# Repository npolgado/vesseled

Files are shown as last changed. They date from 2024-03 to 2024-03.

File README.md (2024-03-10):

# vesseled
addressable led code and hardware source. using addressable LEDS and creating a custom board to control and productize

Hardware:
- [x] Base prototyped idea
- [ ] Create a custom board to control addressable LEDS

Software:
- [x] Basic LED control
- [ ] track mouse poisition
- [ ] more input based lighting

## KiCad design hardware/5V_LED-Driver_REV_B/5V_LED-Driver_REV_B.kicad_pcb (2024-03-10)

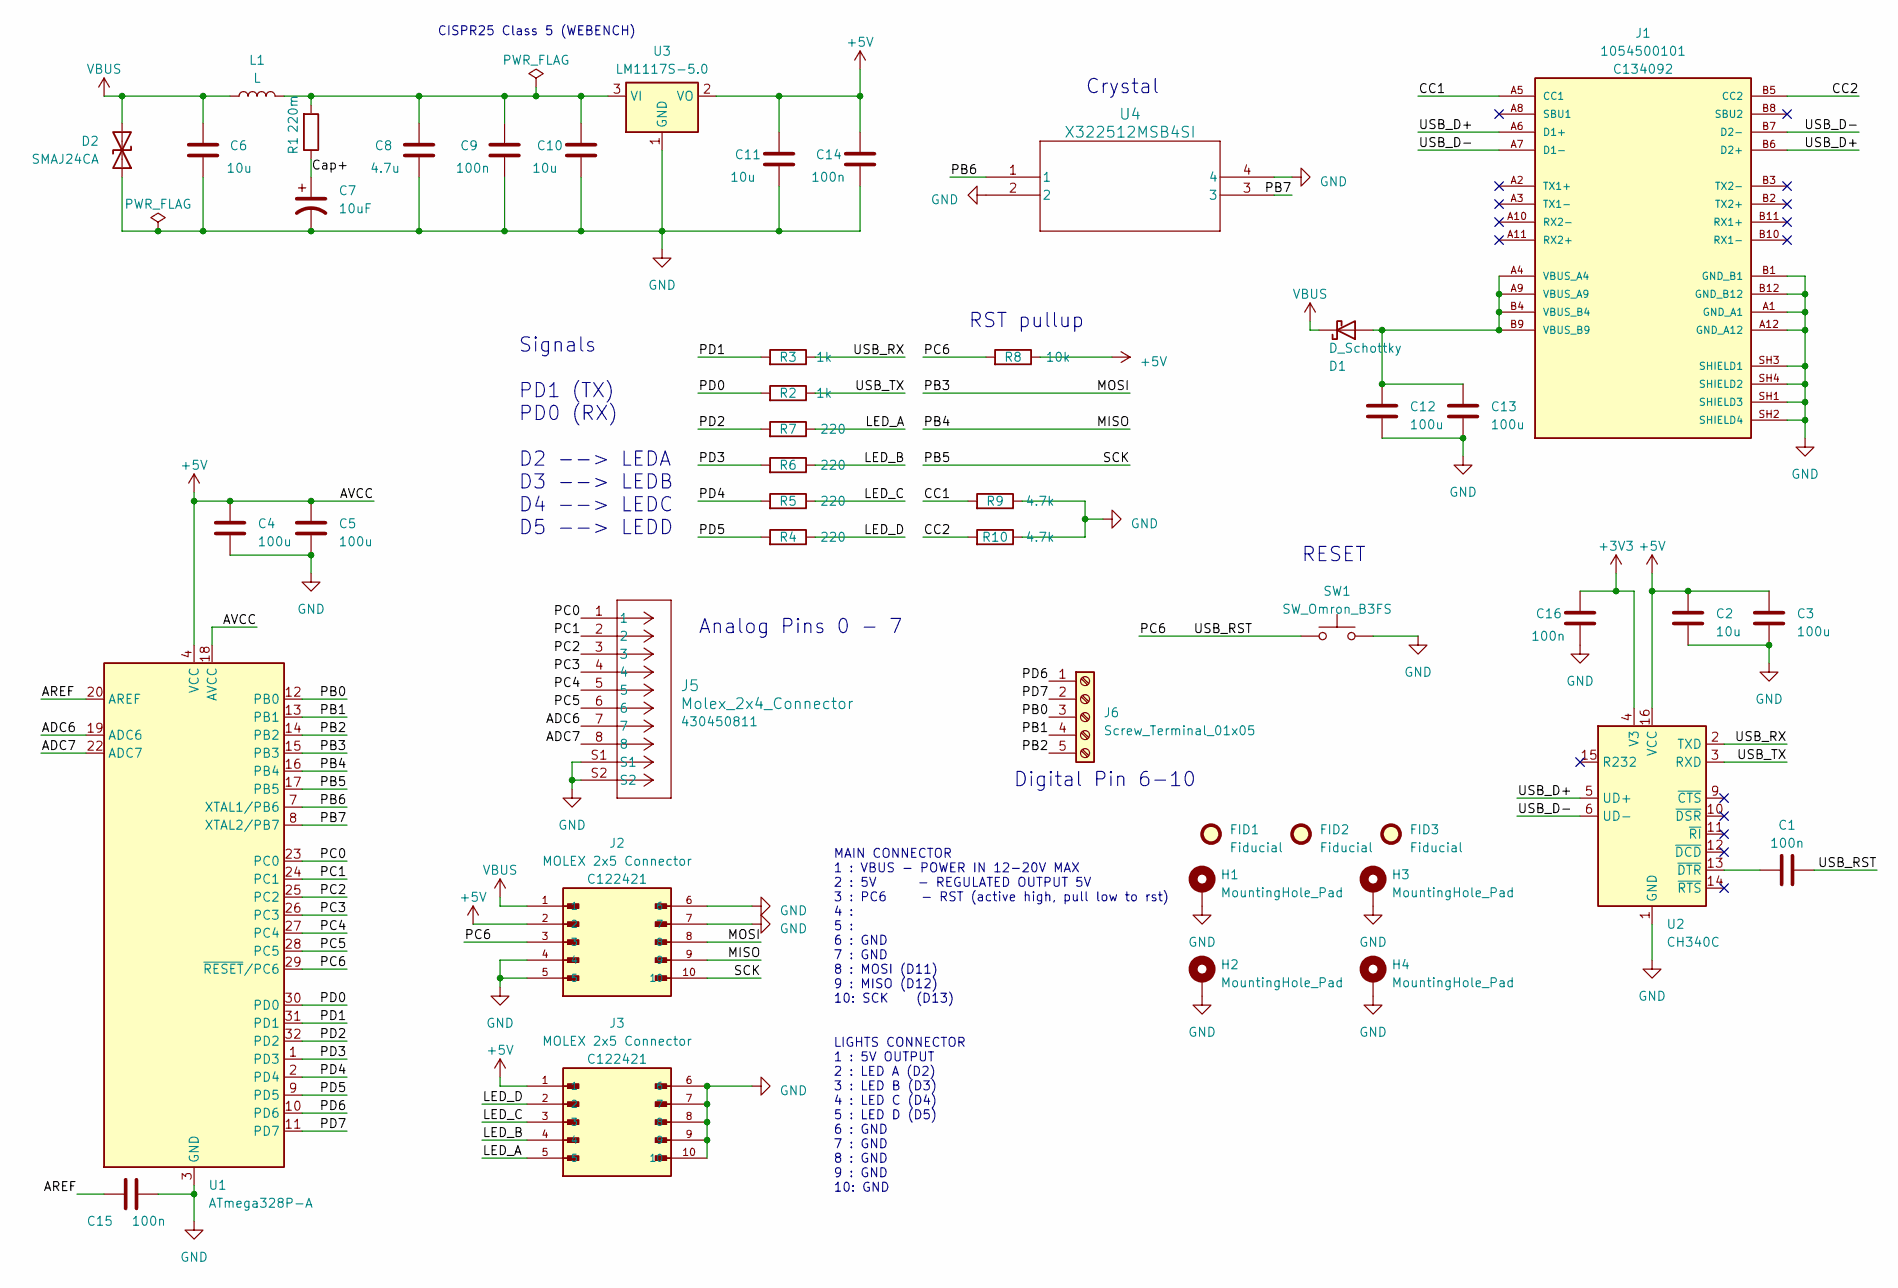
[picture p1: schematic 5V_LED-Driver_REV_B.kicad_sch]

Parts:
C1: 100n; C_0603_1608Metric
C2: 10u; C_0603_1608Metric
C3, C4, C5, C12, C13: 100u; C_0603_1608Metric
C6: 10u; L_1210_3225Metric; Manufacturer Part Number GRM32ER71H106KA12L; JLCPCB Part # C77102
C7: 10uF; CP_Elec_6.3x5.9; Manufacturer Part Number 50SVPF10M; JLCPCB Part # C2162323
C8: 4.7u; C_1206_3216Metric; Manufacturer Part Number GRM31CR71H475KA12L; JLCPCB Part # C77096
C9, C14, C15, C16: 100n; C_0603_1608Metric; Manufacturer Part Number GRM188R71H104KA93D; JLCPCB Part # C77055
C10, C11: 10u; C_0603_1608Metric; Manufacturer Part Number GRM188R71H104KA93D; JLCPCB Part # C77055
D1: D_Schottky; D_SMA
D2: SMAJ24CA; D_SMA; Manufacturer Part Number SMAJ24CA; JLCPCB Part # C148223
FID1, FID2, FID3: Fiducial; Fiducial_1mm_Mask2mm
H1, H2, H3, H4: MountingHole_Pad; MountingHole_3.2mm_M3_DIN965_Pad
J1: 1054500101; MOLEX_1054500101; PARTREV A7; JLCPCB Part # C134092
J2, J3: MOLEX 2x5 Connector; MOLEX_430451000; PARTREV G; JLCPCB Part # C122421
J5: Molex_2x4_Connector; MFG PN 430450811
J6: Screw_Terminal_01x05; TerminalBlock_bornier-5_P5.08mm
L1: L; L_0805_2012Metric; Manufacturer Part Number IHLP1212BZERR22M11; JLCPCB Part # C499512
R1: 220m; R_0603_1608Metric; Manufacturer Part Number RL0603FR-070R22L; JLCPCB Part # C326952
R2, R3: 1k; R_0603_1608Metric
R4, R5, R6, R7: 220; R_0603_1608Metric
R8: 10k; R_0603_1608Metric
R9, R10: 4.7k; R_0603_1608Metric
SW1: SW_Omron_B3FS; SW_SPST_Omron_B3FS-100xP
U1: ATmega328P-A; TQFP-32_7x7mm_P0.8mm
U2: CH340C; SOIC-16_3.9x9.9mm_P1.27mm
U3: LM1117S-5.0; TO-263-3_TabPin2
U4: X322512MSB4SI; SMD_2MSB4SI_YXC

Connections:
+3V3: C16.1, U2.4 (V3)
+5V: C2.1, C3.1, C4.1, C5.1, C11.1, C14.1, J2.2, J3.1, R8.1, U1.4 (VCC), U1.6 (VCC), U1.18 (AVCC), U2.16 (VCC), U3.2 (VO)
/ADC6: J5.7, U1.19 (ADC6)
/ADC7: J5.8, U1.22 (ADC7)
/AREF: C15.1, U1.20 (AREF)
/CC1: J1.A5 (CC1), R9.2
/CC2: J1.B5 (CC2), R10.2
/Cap+: C7.1, R1.1
/LED_A: J3.5, R7.1
/LED_B: J3.4, R6.1
/LED_C: J3.3, R5.1
/LED_D: J3.2, R4.1
/MISO: J2.9, U1.16 (PB4)
/MOSI: J2.8, U1.15 (PB3)
/PB0: J6.3, U1.12 (PB0)
/PB1: J6.4, U1.13 (PB1)
/PB2: J6.5, U1.14 (PB2)
/PB5: J2.10, U1.17 (PB5)
/PB6: U1.7 (XTAL1/PB6), U4.1
/PB7: U1.8 (XTAL2/PB7), U4.3
/PC0: J5.1, U1.23 (PC0)
/PC1: J5.2, U1.24 (PC1)
/PC2: J5.3, U1.25 (PC2)
/PC3: J5.4, U1.26 (PC3)
/PC4: J5.5, U1.27 (PC4)
/PC5: J5.6, U1.28 (PC5)
/PC6: C1.1, J2.3, R8.2, SW1.1, U1.29 (~RESET/PC6)
/PD0: R2.2, U1.30 (PD0)
/PD1: R3.2, U1.31 (PD1)
/PD2: R7.2, U1.32 (PD2)
/PD3: R6.2, U1.1 (PD3)
/PD4: R5.2, U1.2 (PD4)
/PD5: R4.2, U1.9 (PD5)
/PD6: J6.1, U1.10 (PD6)
/PD7: J6.2, U1.11 (PD7)
/USB_D+: J1.A6 (D1+), J1.B6 (D2+), U2.5 (UD+)
/USB_D-: J1.A7 (D1-), J1.B7 (D2-), U2.6 (UD-)
/USB_RX: R3.1, U2.2 (TXD)
/USB_TX: R2.1, U2.3 (RXD)
GND: C2.2, C3.2, C4.2, C5.2, C6.2, C7.2, C8.2, C9.2, C10.2, C11.2, C12.2, C13.2, C14.2, C15.2, C16.2, D2.1 (A1), H1.1, H2.1, H3.1, H4.1, J1.A1 (GND_A1), J1.A12 (GND_A12), J1.B1 (GND_B1), J1.B12 (GND_B12), J1.SH1 (SHIELD3), J1.SH2 (SHIELD4), J1.SH3 (SHIELD1), J1.SH4 (SHIELD2), J2.4, J2.5, J2.6, J2.7, J3.6, J3.7, J3.8, J3.9, J3.10, J5.S1, J5.S2, R9.1, R10.1, SW1.2, U1.3 (GND), U1.5 (GND), U1.21 (GND), U2.1 (GND), U3.1 (GND), U4.2, U4.4
unnamed: C8.1, C9.1, C10.1, L1.2, R1.2, U3.3 (VI)
unnamed: C12.1, C13.1, D1.2 (A), J1.A4 (VBUS_A4), J1.A9 (VBUS_A9), J1.B4 (VBUS_B4), J1.B9 (VBUS_B9)
unnamed: C1.2, U2.13 (~DTR)
VBUS: C6.1, D1.1 (K), D2.2 (A2), J2.1, L1.1

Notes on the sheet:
Crystal
RST pullup
CISPR25 Class 5 (WEBENCH)
Digital Pin 6-10
MAIN CONNECTOR 1 : VBUS - POWER IN 12-20V MAX 2 : 5V - REGULATED OUTPUT 5V 3 : PC6 - RST (active high, pull low to rst) 4 : 5 : 6 : GND 7 : GND 8 : MOSI (D11) 9 : MISO (D12) 10: SCK (D13)
Analog Pins 0 - 7
RESET
Signals PD1 (TX) PD0 (RX) D2 --> LEDA D3 --> LEDB D4 --> LEDC D5 --> LEDD
LIGHTS CONNECTOR 1 : 5V OUTPUT 2 : LED A (D2) 3 : LED B (D3) 4 : LED C (D4) 5 : LED D (D5) 6 : GND 7 : GND 8 : GND 9 : GND 10: GND

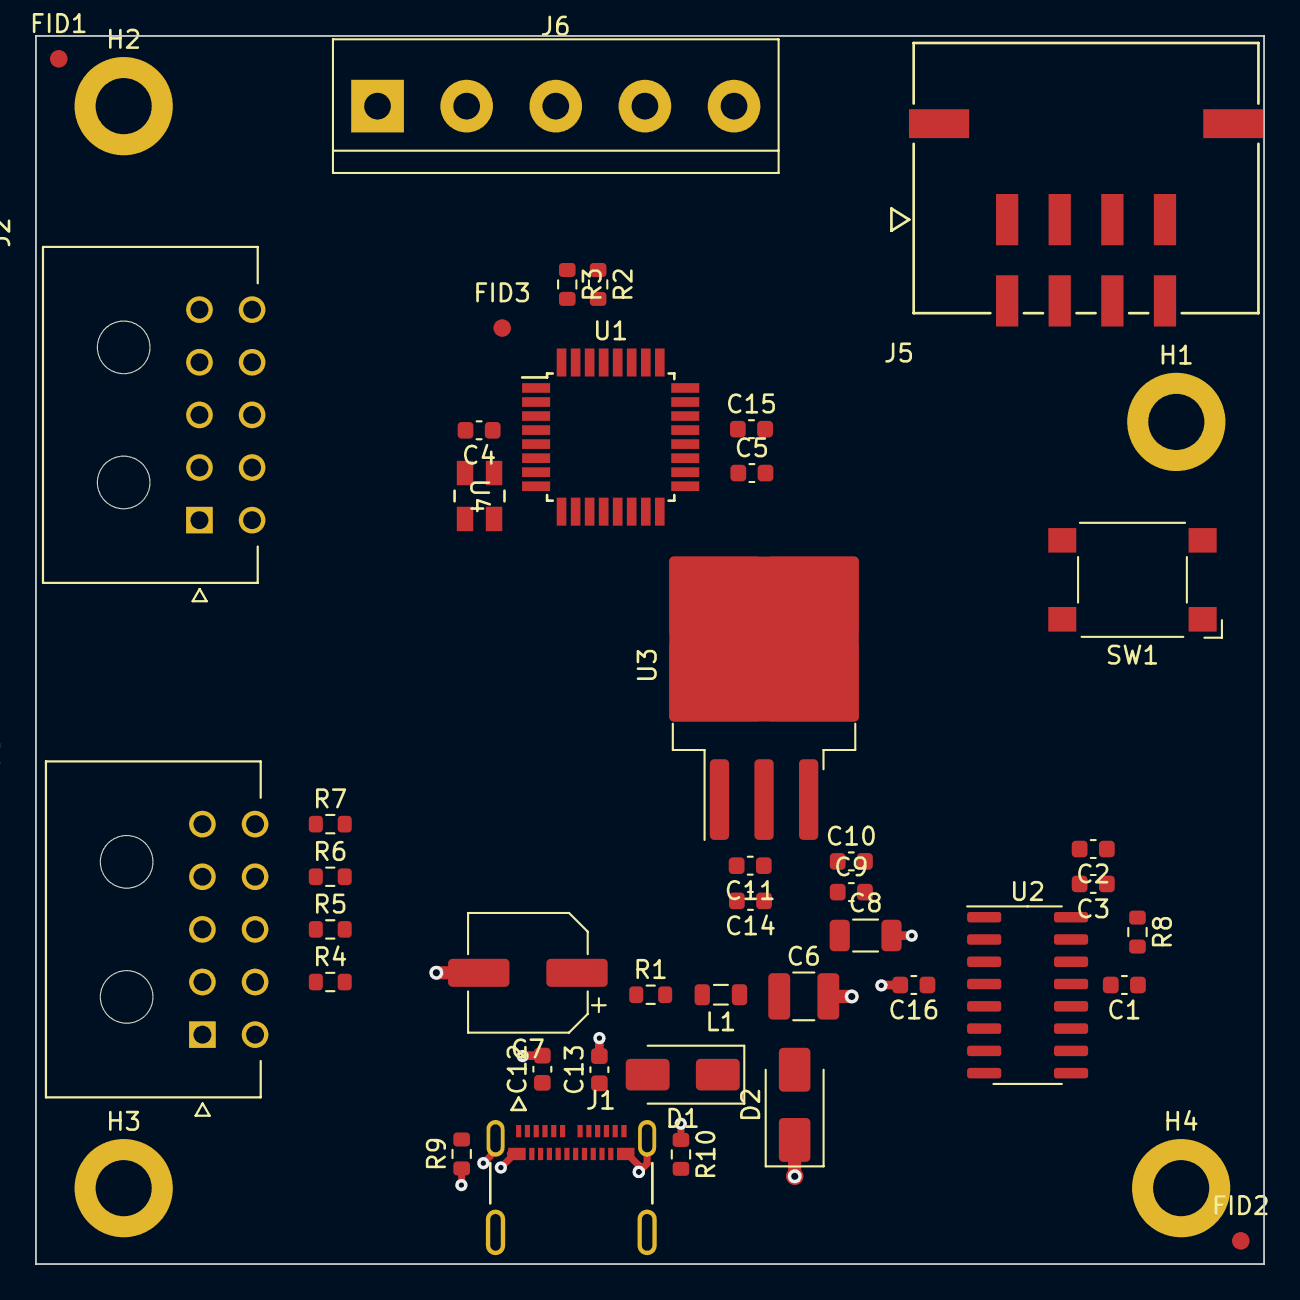
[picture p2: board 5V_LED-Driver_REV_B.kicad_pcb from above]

Board: 4 copper layers, 70.0 x 70.0 mm, 46 parts (0 on the bottom side), 44 nets.

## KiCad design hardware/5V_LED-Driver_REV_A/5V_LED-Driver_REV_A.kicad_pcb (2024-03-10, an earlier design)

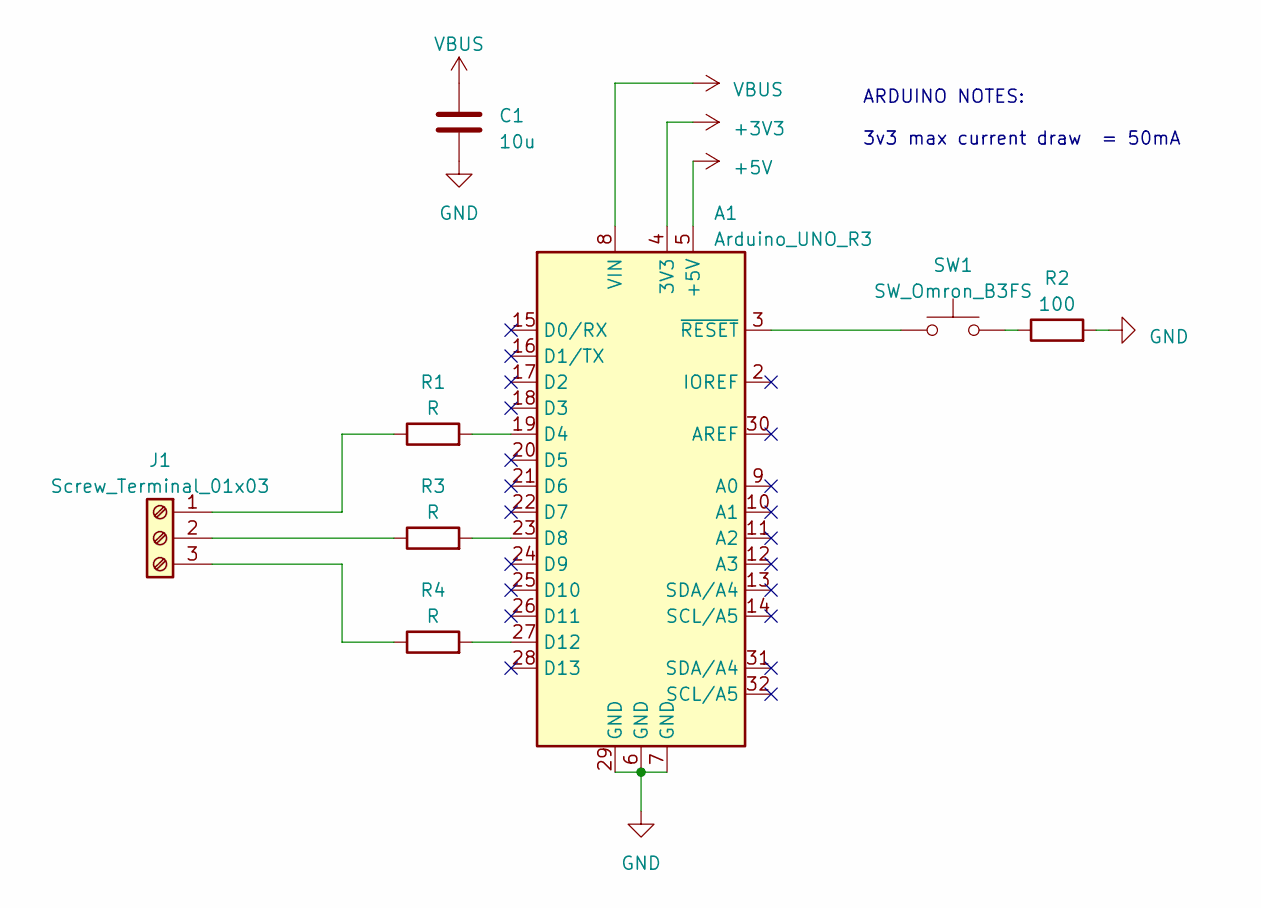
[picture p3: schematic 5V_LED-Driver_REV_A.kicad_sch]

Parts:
A1: Arduino_UNO_R3
C1: 10u; C_0603_1608Metric
J1: Screw_Terminal_01x03; TerminalBlock_Phoenix_MKDS-3-3-5.08_1x03_P5.08mm_Horizontal
R1, R3, R4: R; R_0603_1608Metric
R2: 100; R_0603_1608Metric
SW1: SW_Omron_B3FS; SW_SPST_Omron_B3FS-100xP

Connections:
+3V3: A1.4 (3V3)
+5V: A1.5 (+5V)
GND: A1.6 (GND), A1.7 (GND), A1.29 (GND), C1.2, R2.2
unnamed: A1.19 (D4), R1.2
unnamed: A1.23 (D8), R3.2
unnamed: A1.27 (D12), R4.2
unnamed: A1.3 (~RESET), SW1.1
unnamed: J1.1, R1.1
unnamed: J1.2, R3.1
unnamed: J1.3, R4.1
unnamed: R2.1, SW1.2
VBUS: A1.8 (VIN), C1.1

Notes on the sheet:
ARDUINO NOTES: 3v3 max current draw = 50mA

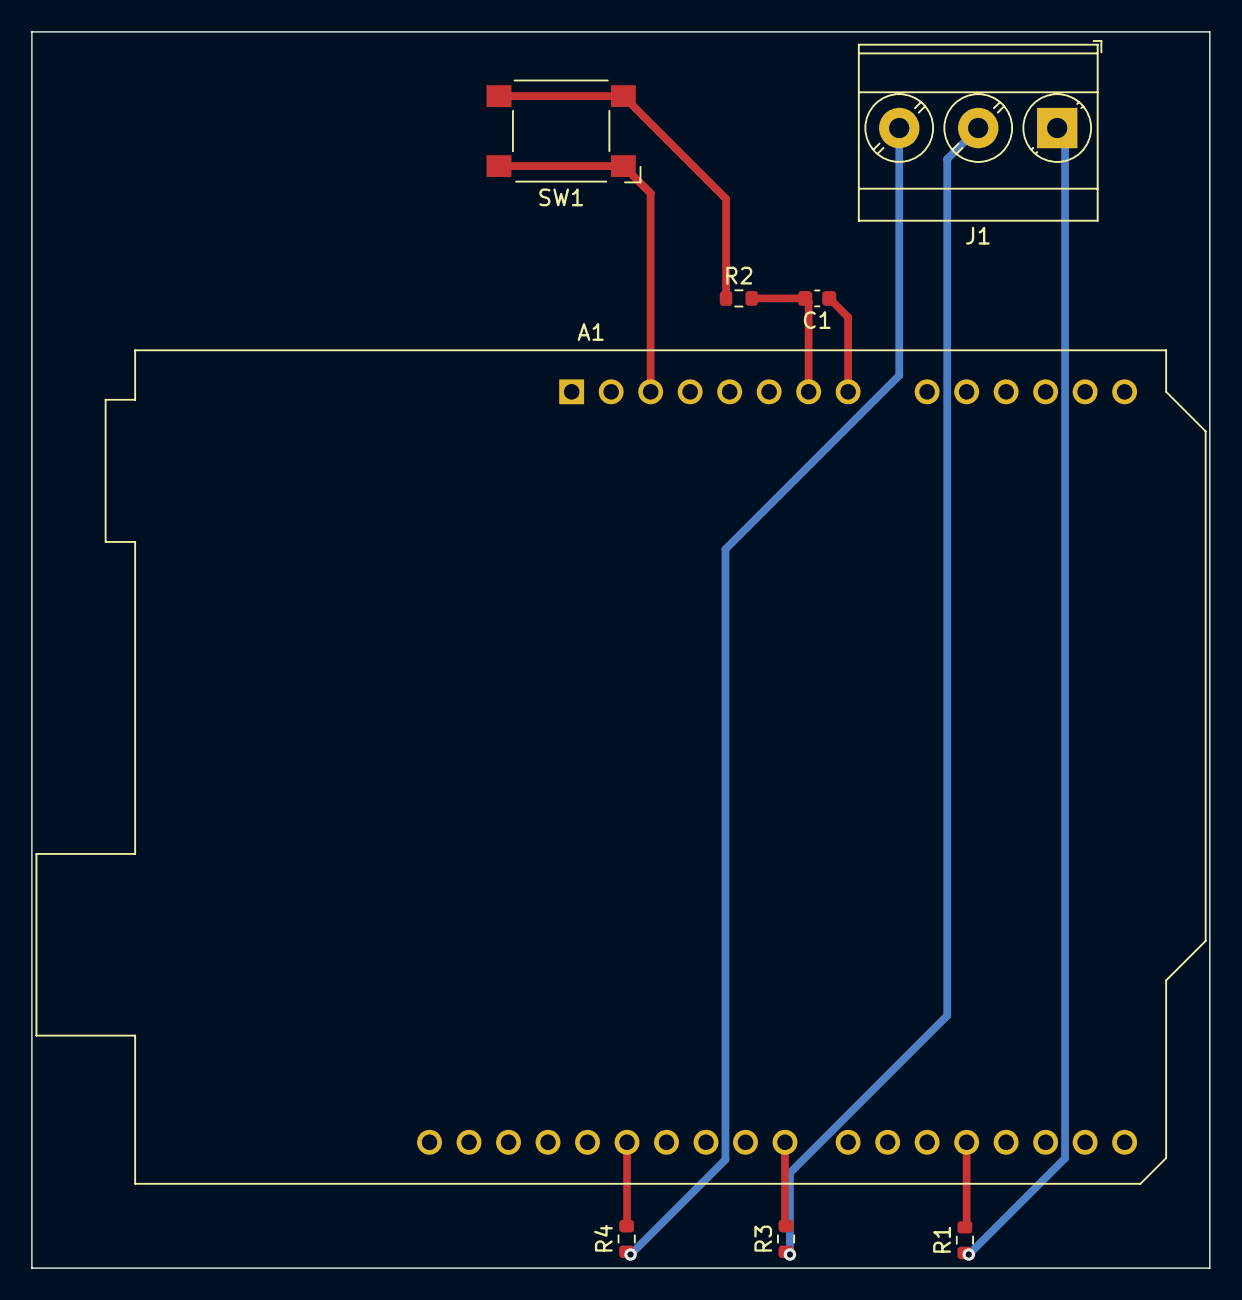
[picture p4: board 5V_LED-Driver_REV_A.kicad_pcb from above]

Board: 2 copper layers, 75.7 x 79.5 mm, 8 parts (0 on the bottom side), 10 nets.

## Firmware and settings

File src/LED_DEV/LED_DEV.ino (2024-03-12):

#include <FastLED.h>

FASTLED_USING_NAMESPACE

////////////////////////////////////////////////////////////////////////////////////////////////////////////////////////////////
// GEN CONTROL
////////////////////////////////////////////////////////////////////////////////////////////////////////////////////////////////

#define DATA_PIN    7
#define LED_TYPE    WS2812B
#define COLOR_ORDER GRB
#define NUM_LEDS    114 // 192 - 114 = 78 LED's left
#define ARRAY_SIZE(A) (sizeof(A) / sizeof((A)[0]))

#define BRIGHTNESS         25
#define FRAMES_PER_SECOND  120

#define COLOR_SHIFT_DELAY   15
#define SECONDS_PER_PATTERN 15

#define MONITOR_MIDPOINT 53

// COOLING: How much does the air cool as it rises?
// Less cooling = taller flames.  More cooling = shorter flames.
// Default 55, suggested range 20-100 
#define COOLING  100

// SPARKING: What chance (out of 255) is there that a new spark will be lit?
// Higher chance = more roaring fire.  Lower chance = more flickery fire.
// Default 120, suggested range 50-200.
#define SPARKING 200

#define BPM 62

#define NUM_JUNGLE 16

#define HAPTIC_TIMEOUT_SECONDS 1

bool gReverseDirection = false;
bool is_daytime = false;

CRGB leds[NUM_LEDS];
CRGBPalette16 gPal;

uint8_t gCurrentPatternNumber = 0; // Index number of which pattern is current

uint8_t gCurrentPatternNumberL = 0; // Index number of which pattern is current
uint8_t gCurrentPatternNumberR = 0; // Index number of which pattern is current

uint8_t gHue = 0; // rotating "base color" used by many of the patterns

unsigned long lastSerialMessageTime = 0; // Variable to store the last time a serial message was sent

int random_num = 30;

////////////////////////////////////////////////////////////////////////////////////////////////////////////////////////////////
// SETUP
////////////////////////////////////////////////////////////////////////////////////////////////////////////////////////////////

void setup() {
  delay(500);
  FastLED.addLeds<LED_TYPE,DATA_PIN,COLOR_ORDER>(leds, NUM_LEDS).setCorrection(TypicalLEDStrip);
  FastLED.setBrightness(BRIGHTNESS);
  gPal = HeatColors_p;

  for (int i = 0; i < NUM_LEDS; i++) {
    leds[i] = CRGB::Red;
  }
  FastLED.show();
  delay(500);
  FastLED.clear();
  FastLED.show();
  delay(500);

  Serial.begin(115200);
  while(!Serial) { ; }
  Serial.setTimeout(1000);
}

typedef void (*SimplePatternList[])();
typedef void (*SimplePatternList2[])(int start , int end);
// List of patterns to cycle through.  Each is defined as a separate function below.
SimplePatternList gPatterns = {sinelon, rainbowWithGlitter, juggle, bpm, confetti, fire};

SimplePatternList2 gPatternsL = {bpm_range, rainbox_range, juggle_bpm_range, sinelon_range, confetti_range, solid_fill_range};
SimplePatternList2 gPatternsR = {confetti_range, solid_fill_range, rainbox_range, juggle_bpm_range, bpm_range, sinelon_range};

////////////////////////////////////////////////////////////////////////////////////////////////////////////////////////////////
// MAIN
////////////////////////////////////////////////////////////////////////////////////////////////////////////////////////////////

void loop()
{

  // Check if serial message to take
  if (Serial.available() > 0) {
    // Read the incoming byte:
    char incomingByte = Serial.read();
    // Say what you got:
    Serial.print("Arduino Recieved: ");
    Serial.println(incomingByte);

    // Update the lastSerialMessageTime with the current time
    lastSerialMessageTime = millis();

    // Rest of your code...
    // if the incoming byte decoded in utf-8 is 1, then set the pattern to solid fill
    if (incomingByte == '1') {
      gCurrentPatternNumberL = 5;
    }
    else {
      gCurrentPatternNumberL = gCurrentPatternNumber;
    }

    if (incomingByte == '2') {
      gCurrentPatternNumberR = 1;
    }
    else {
      gCurrentPatternNumberR = gCurrentPatternNumber;
    }
  }
  
  int calc_time_seconds = (millis() - lastSerialMessageTime) / 1000;
  
  // if the calculated time is greater than the haptic timeout, then set the pattern to their parent index
  if (calc_time_seconds > HAPTIC_TIMEOUT_SECONDS) {
    gCurrentPatternNumberL = gCurrentPatternNumber;
    gCurrentPatternNumberR = gCurrentPatternNumber;
  }


  // random split
  // gPatternsL[gCurrentPatternNumber](0, random_num);
  // gPatternsR[gCurrentPatternNumber](random_num+1, NUM_LEDS);

  // // monitor split
  // gPatternsL[gCurrentPatternNumberL](0, MONITOR_MIDPOINT);
  // gPatternsR[gCurrentPatternNumberR](MONITOR_MIDPOINT+1, NUM_LEDS);

  // // send the 'leds' array out to the actual LED strip
  // FastLED.show();  
  // // insert a delay to keep the framerate modest
  // FastLED.delay(1000/FRAMES_PER_SECOND); 

  // do some periodic updates
  EVERY_N_MILLISECONDS( COLOR_SHIFT_DELAY ) { gHue++; } // slowly cycle the "base color" through the rainbow
  EVERY_N_SECONDS( SECONDS_PER_PATTERN )
  { 
    random_num = random(0, NUM_LEDS); 
    // random_num2 = random(random_num, NUM_LEDS);
    nextPattern();
  }
  EVERY_N_SECONDS( 600 ) { gReverseDirection = !gReverseDirection; } 
  EVERY_N_HOURS( 12 ) { is_daytime = !is_daytime; } 
}


void nextPattern()
{
  fadeToBlackBy( leds, NUM_LEDS, 1000);
  // add one to the current pattern number, and wrap around at the end
  gCurrentPatternNumber = (gCurrentPatternNumber + 1) % ARRAY_SIZE( gPatterns);
}

void solid_fill()
{
  // use fast LED to fill the strip with a solid color
  // use the hue shift to change the color
  fill_solid(leds, NUM_LEDS, CHSV(gHue, 255, 255));
}

void solid_fill_range(int start, int end)
{
  // use fast LED to fill the strip with a solid color
  // use the hue shift to change the color
  for( int i = start; i < end; ++i)
  {
    leds[i] = CRGB(gHue, 255, 255);
  }
}

void fire()
{
  random16_add_entropy( random());
  // Array of temperature readings at each simulation cell
  static uint8_t heat[NUM_LEDS];

    // Step 1.  Cool down every cell a little
    for( int i = 0; i < NUM_LEDS; i++) {
      heat[i] = qsub8( heat[i],  random8(0, ((COOLING * 10) / NUM_LEDS) + 2));
    }
  
    // Step 2.  Heat from each cell drifts 'up' and diffuses a little
    for( int k= NUM_LEDS - 1; k >= 2; k--) {
      heat[k] = (heat[k - 1] + heat[k - 2] + heat[k - 2] ) / 3;
    }
    
    // Step 3.  Randomly ignite new 'sparks' of heat near the bottom
    if( random8() < SPARKING ) {
      int y = random8(7);
      heat[y] = qadd8( heat[y], random8(160,255) );
    }

    // Step 4.  Map from heat cells to LED colors
    for( int j = 0; j < NUM_LEDS; j++) {
      // Scale the heat value from 0-255 down to 0-240
      // for best results with color palettes.
      uint8_t colorindex = scale8( heat[j], 240);
      CRGB color = ColorFromPalette( gPal, colorindex);
      int pixelnumber;
      if( gReverseDirection ) {
        pixelnumber = (NUM_LEDS-1) - j;
      } else {
        pixelnumber = j;
      }
      leds[pixelnumber] = color;
    } 
}

void rainbow() 
{
  // FastLED's built-in rainbow generator
  fill_rainbow( leds, NUM_LEDS, gHue, 7);
}

void rainbox_range(int start, int end)
{
  CHSV hsv;
  hsv.hue = gHue;
  hsv.val = 255;
  hsv.sat = 240;
  for( int i = start; i < end; ++i) {
      leds[i] = hsv;
      hsv.hue += 7;
  }
}

void rainbowWithGlitter() 
{
  // built-in FastLED rainbow, plus some random sparkly glitter
  rainbow();
  addGlitter(50);
}

void addGlitter( fract8 chanceOfGlitter) 
{
  if( random8() < chanceOfGlitter) {
    leds[ random16(NUM_LEDS) ] += CRGB::White;
  }
}

void confetti() 
{
  // random colored speckles that blink in and fade smoothly
  fadeToBlackBy( leds, NUM_LEDS, 10);
  int pos = random16(NUM_LEDS);
  leds[pos] += CHSV( gHue + random8(64), 200, 255);
}

void confetti_range(int start, int end) 
{
  // pointer to LED at MONITOR_MIDPOINT+1 --> NUM_LEDS
  int total = abs(end - start);
  CRGB* ledPtr = &leds[start];

  // random colored speckles that blink in and fade smoothly
  fadeToBlackBy(ledPtr, total, 10);
  int pos = random16(start, end);
  leds[pos] += CHSV( gHue + random8(64), 200, 255);
}

void sinelon()
{
  // a colored dot sweeping back and forth, with fading trails
  fadeToBlackBy( leds, NUM_LEDS, 20);
  int pos = beatsin16( 13, 0, NUM_LEDS-1 );
  leds[pos] += CHSV( gHue, 255, 192);
}

void sinelon_range(int start, int end)
{
  // a colored dot sweeping back and forth, with fading trails
  fadeToBlackBy( leds, NUM_LEDS, 20);
  int pos = beatsin16( 13, start, end-1 );
  leds[pos] += CHSV( gHue, 255, 192);
}

void bpm()
{
  // colored stripes pulsing at a defined Beats-Per-Minute (BPM)
  uint8_t BeatsPerMinute = 62;
  CRGBPalette16 palette = PartyColors_p;
  uint8_t beat = beatsin8( BeatsPerMinute, 64, 255);
  for( int i = 0; i < NUM_LEDS; i++) {
    leds[i] = ColorFromPalette(palette, gHue+(i*2), beat-gHue+(i*10));
  }
}

void bpm_range(int start, int end)
{
  // colored stripes pulsing at a defined Beats-Per-Minute (BPM)
  CRGBPalette16 palette = PartyColors_p;
  uint8_t beat = beatsin8( BPM, 64, 255);
  for( int i = start; i < end; i++) {
    leds[i] = ColorFromPalette(palette, gHue+(i*2), beat-gHue+(i*10));
  }
}

void juggle() {
  // eight colored dots, weaving in and out of sync with each other
  fadeToBlackBy( leds, NUM_LEDS, 20);
  uint8_t dothue = 0;
  for( int i = 0; i < 8; i++) {
    leds[beatsin16( i+7, 0, NUM_LEDS-1 )] |= CHSV(dothue, 200, 255);
    dothue += 32;
  }
}

void juggle_bpm_range(int start, int end) {
  // eight colored dots, weaving in and out of sync with each other
  fadeToBlackBy( leds, NUM_LEDS, 20);
  uint8_t dothue = 0;
  for( int i = 0; i < NUM_JUNGLE; i++) {
    leds[beatsin16( i+7, start, end-1 )] |= CHSV(dothue, 200, 255);
    dothue += 32;
  }
}

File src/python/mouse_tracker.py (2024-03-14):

import pyautogui
import time
import serial
from serial import Serial
from scipy.interpolate import interp1d

top_strip_map_x = interp1d([1919,-1920],[0,144])
top_strip_map_y = interp1d([0,1080],[0,255])

RATE = 0.1
command = "0x2E 0x09 \n"

# print serial ports
import serial.tools.list_ports
ports = serial.tools.list_ports.comports()
print(ports)
for port, desc, hwid in sorted(ports):
    print("{}: {} [{}]".format(port, desc, hwid))

def get_cursor_position():
    # Get the current mouse position
    x, y = pyautogui.position()
    return x, y

if __name__ == "__main__":
    # Get Cursor Position
    # x_coord, y_coord = get_cursor_position()
        
    try:
        with serial.Serial(
            port="COM4",
            baudrate=115200,
            bytesize=8,
            parity='N',
            stopbits=1,
            timeout=1) as ser:
            # ser.write(serial.to_bytes(command.encode()))
            while True:
                # print any received data
                if ser.in_waiting > 0:
                    try:
                        print(ser.readline())
                    except Exception as e:
                        pass

                # Get Cursor Position
                x_coord, y_coord = get_cursor_position()
                
                top_strip_x = int(top_strip_map_x(x_coord))
                top_strip_y = int(top_strip_map_y(y_coord))

                top_x_str = bytes([top_strip_x])
                top_y_str = bytes([top_strip_y])

                # print(f"Top Strip X: {top_x_str} Y: {top_y_str}")

                ser.write(top_x_str)
                ser.write(top_y_str)
                time.sleep(RATE)

    except Exception as e:
        print(e)
        exit()
